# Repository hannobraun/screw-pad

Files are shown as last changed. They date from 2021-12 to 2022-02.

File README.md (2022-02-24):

# Screw Pad

## About

I once needed to drill into a rather large aluminium plate using a very small drill press. To do that, I needed to prop up the three corners of the plate that didn't fit on the drill press table. That's when the idea for the Screw Pad was born: A finely height-adjustable support for light workshop duties.

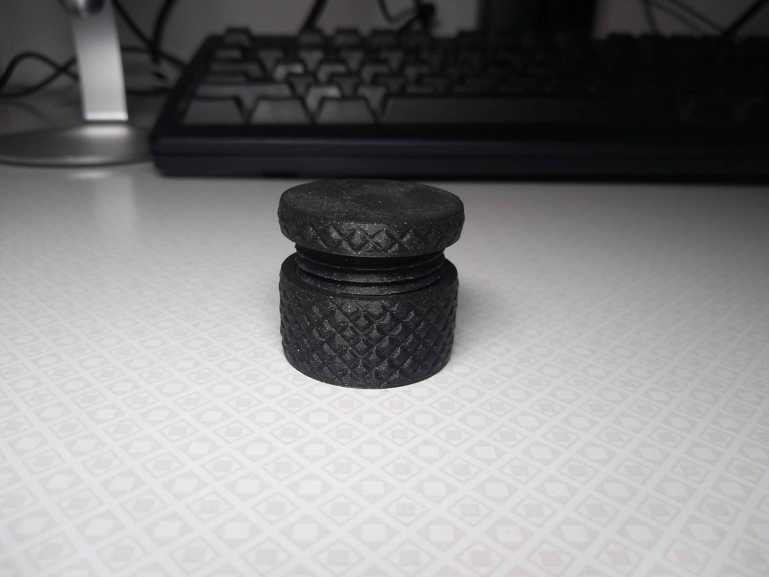
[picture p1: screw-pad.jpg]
a Screw Pad on a desk


For a while, I planned to sell this as a product. Not because I though it would be successful. I have no indication that anyone ever needed this, except for me, that one time. But because it seemed like a simple enough product to design and manufacture (using a 3D printer), and I wanted to learn about the logistics of selling physical products online.

My product ideas have since taken [a different turn](https://github.com/hannobraun/notebook), so I decided to just make this repository public and leave it be.

## Status

This is usable, but a bit loose on my printer. The fit between the screw and nut could use some optimization.

## Ideas

I've had two main ideas for further evolution of this product.

### Rubber pads on the bottom

Add a recessed area to the bottom and glue some kind of rubber pad on there. I figured that this would increase traction. Although I haven't done testing to determine if this is actually needed.

### Sideways access using screw driver

During my testing, it became obvious that adjusting the Screw Pad was pretty difficult. The Screw Pad is pretty low, so if you put it under something, it can be hard to fit your hands in there to get to it.

I had this idea of using a worm gear mechanism to allow for adjusting the Screw Pad with a screw driver from the side. The problem with this is, that would take pretty long to adjust. And a worm gear is not backdrivable, so you can no longer just spin the top.

Maybe there's a decent idea in there somewhere. I don't know.

### Range extension through telescopic mechanism

Another problem is that the adjustable height range is relatively narrow. A factor of two is the upper limit for the ratio between the lengths of the fully contracted and the fully extended states.

I figured that maybe this could be addressed using a [multi-stage telescopic screw actuator](https://www.youtube.com/watch?v=nmyvMkfxtbo), but never got as far as designing that.

## License

This product is open source, licensed under the terms of the [Zero Clause BSD License] (0BSD, for short). This basically means you can do anything with it, without any restrictions, but you can't hold the authors liable for problems.

See [LICENSE.md] for full details.

[Zero Clause BSD License]: https://opensource.org/licenses/0BSD
[LICENSE.md]: LICENSE.md

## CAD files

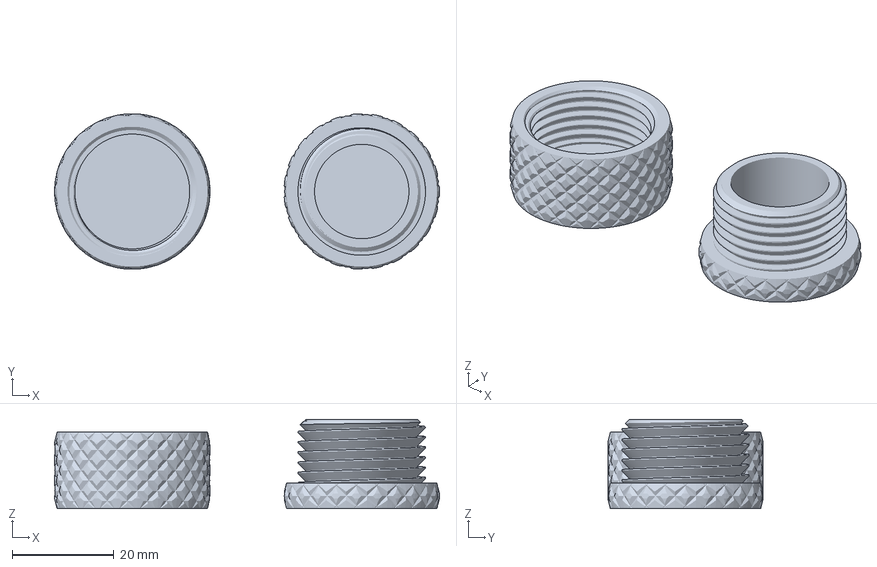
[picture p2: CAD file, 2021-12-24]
prints/v4 - Prototype.3mf
75.5 x 30.5 x 17.5 mm

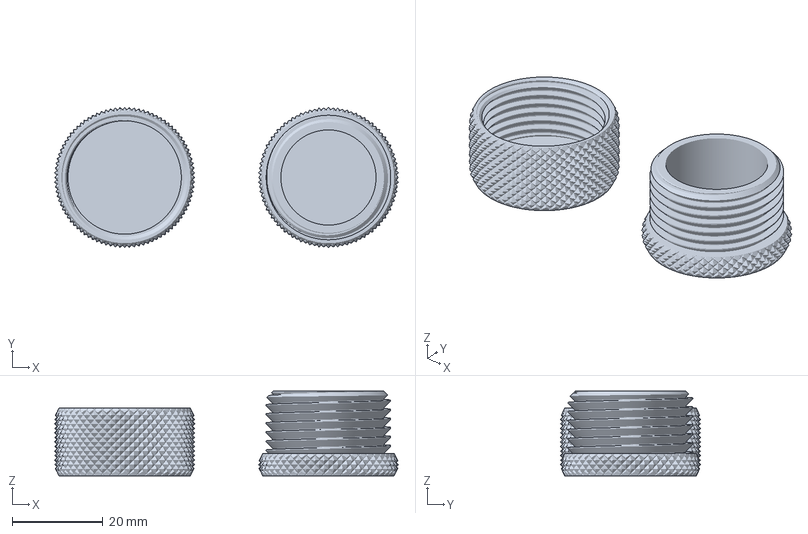
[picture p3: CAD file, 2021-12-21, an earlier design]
prints/v3 - Prototype.3mf
76.0 x 31.0 x 18.8 mm

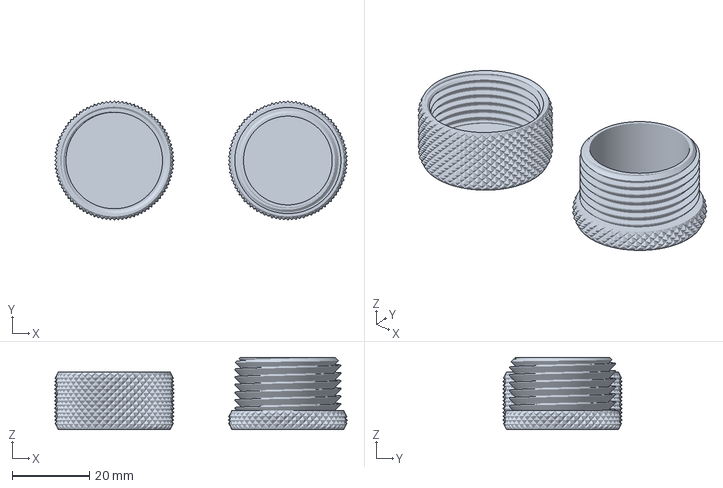
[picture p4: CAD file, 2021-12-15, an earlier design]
prints/v2 - Prototype.3mf
76.0 x 31.0 x 18.8 mm

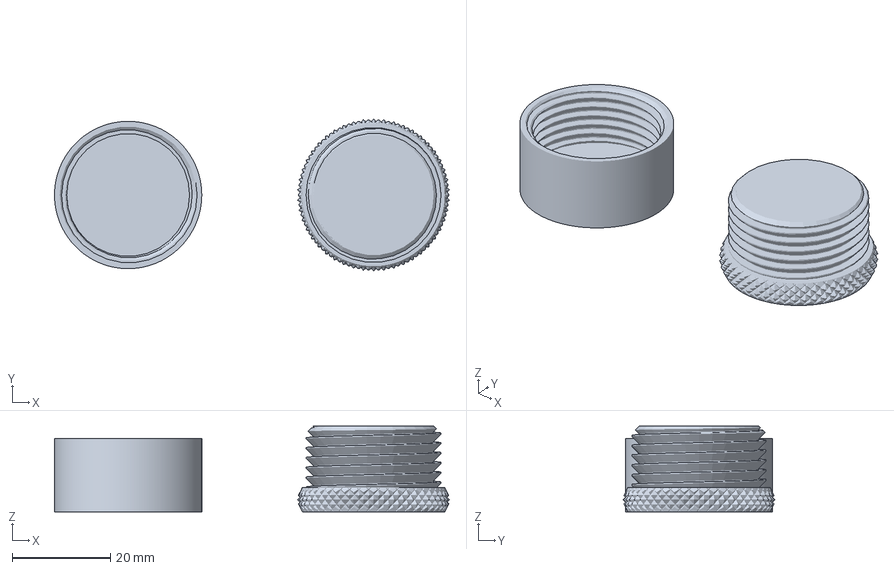
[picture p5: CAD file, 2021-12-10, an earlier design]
prints/v1 - Prototype.3mf
80.5 x 31.0 x 17.5 mm

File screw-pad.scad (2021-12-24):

include <libs/BOSL/constants.scad>
use <libs/BOSL/threading.scad>

use <libs/knurledFinishLib_v2.scad>


height            = 15;
material_strength =  2.5;
head_height       =  5;

outer_diameter = 30;
inner_diameter = outer_diameter - 2 * material_strength;

thread_height = height - material_strength;
thread_pitch  = 2;

offset_x = outer_diameter * 0.75;


$fn = 360;


nut();
screw();


module nut() {
    translate([-offset_x, 0, 0])
    union() {
        // Base
        difference() {
            cylinder(
                // Don't use full outer diamter, to leave some room for the
                // knurling we add below.
                d = outer_diameter - material_strength,
                h = material_strength
            );
            mark();
        }

        translate([0, 0, material_strength])
        difference() {
            // The internal thread, plus some superfluous geometry we'll be
            // removing in the next step.
            //
            // TASK: This bevels the thread on both sides, although that's only
            //       necessary on the upper side. According to the
            //       documentation, there should be separate `bevel1` and
            //       `bevel2` arguments to enable this, but those don't actually
            //       exist.
            buttress_threaded_nut(
                od     = outer_diameter,
                id     = inner_diameter,
                h      = thread_height,
                pitch  = thread_pitch,
                bevel  = true,
                orient = ORIENT_ZNEG,
                align  = V_UP
            );

            // BOSL generates an actual hexagonal nut, which is not what we
            // want. Let's make it a cylinder.
            difference() {
                cylinder(
                    d = outer_diameter * 2,
                    h = thread_height
                );
                cylinder(
                    // Remove more than we have to, to make some room for the
                    // knurling we add below.
                    d = outer_diameter - material_strength,
                    h = thread_height
                );
            }
        }

        // Add knurling.
        difference() {
            cyl_knurled(
                d = outer_diameter,
                h = height
            );
            cylinder(
                d = outer_diameter - material_strength,
                h = height
            );
        }
    }
}

module screw() {
    translate([offset_x, 0, 0])
    difference() {
        union() {
            // The head.
            cyl_knurled(
                d = outer_diameter,
                h = head_height
            );

            // The screw threads.
            translate([0, 0, head_height])
            buttress_threaded_rod(
                d      = inner_diameter,
                l      = thread_height,
                pitch  = thread_pitch,
                bevel2 = true,
                orient = ORIENT_Z,
                align  = V_UP
            );
        }

        // Hollow out the screw, to save material.
        translate([0, 0, material_strength])
        cylinder(
            // We subtract the thread pitch, but we actually need to subtract
            // the height. Still, this should be a good enough approximation.
            d = inner_diameter - 2 * thread_pitch - material_strength,
            h = head_height + thread_height - material_strength
        );
    }
}

module cyl_knurled(d, h) {
    knurled_cyl(
        chg = h,
        cod = d,

        // Knurling parameters
        cwd =  4, // polyhedron width
        csh =  4, // polyhedron height
        cdp =  1, // polyhedron depth
        fsh =  2, // cylinder ends smoothed height
        smt = 50  // knurled surface smoothing amount
    );
}

module mark() {
    lines = [
        "Screw Pad",
        "Hanno Braun",
        "2021-W51 · #4",
        "Made in",
        "Odenwald",
    ];

    size = 2.5;

    linear_extrude(1)
    mirror([1, 0, 0])
    union() {
        for (i = [0 : len(lines) - 1]) {
            translate([0, -(i - 2.0) * size * 1.5, 0])
            text(
                lines[i],
                size = size,
                font = "osifont",
                halign = "center",
                valign = "center"
            );
        }
    }
}

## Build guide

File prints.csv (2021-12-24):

Serial | Quality | Filament | Notes
1 | 0.10mm DETAIL | Prusament PLA
2 | 0.20mm QUALITY | Prusament PLA
3 | 0.10mm DETAIL | Prusament PLA | Min. perimeters: 1
4 | 0.10mm DETAIL | Prusament PLA | Min. perimeters: 1

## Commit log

2021-11-19 Add beginnings of FreeCAD design
    [ScrewPad.FCStd]
2021-11-19 Update model
    [ScrewPad.FCStd]
2021-12-09 Add BOSL library
    [acme_screws.scad, bezier_patches.scad, beziers.scad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]
2021-12-09 Add OpenSCAD model
    [screw-pad.scad]
2021-12-09 Make nut round
    [screw-pad.scad]
2021-12-09 Make nut bottom the same size as rest of nut
    Now that there's not excess material on the rest of the nut, the bottom
    doesn't need to be bigger.
    [screw-pad.scad]
2021-12-09 Move BOSL to `libs/` directory
    [screw-pad.scad]
2021-12-09 Add knurling to head
    [screw-pad.scad]
2021-12-10 Remove FreeCAD files
    [ScrewPad.FCStd]
2021-12-10 Add 3MF file for first prototype print
    [v1 - Prototype.3mf]
2021-12-10 Fix material strength calculation
    [screw-pad.scad]
2021-12-10 Hollow out screw
    [screw-pad.scad]
2021-12-10 Add documentation
    [screw-pad.scad]
2021-12-10 Improve placement
    [screw-pad.scad]
2021-12-14 Add knurling to nut
    [screw-pad.scad]
2021-12-15 Set precision globally
    [screw-pad.scad]
2021-12-15 Add second prototype
    [v2 - Prototype.3mf]
2021-12-15 Add signature
    [screw-pad.scad]
2021-12-20 Add prints file
    [prints.csv]
2021-12-20 Update signature
    [screw-pad.scad]
2021-12-21 Fix inacurracy of screw
    [screw-pad.scad]
2021-12-21 Add prototype #3
    [prints.csv, v3 - Prototype.3mf]
2021-12-23 Increase material strength
    [screw-pad.scad]
2021-12-23 Improve formatting
    [screw-pad.scad]
2021-12-23 Rename module
    [screw-pad.scad]
2021-12-23 Update mark
    [screw-pad.scad]
2021-12-24 Smooth top of knurling pattern
    [screw-pad.scad]
2021-12-24 Make knurling pattern polyhedrons larger
    [screw-pad.scad]
2021-12-24 Add print
    [prints.csv, v4 - Prototype.3mf]
